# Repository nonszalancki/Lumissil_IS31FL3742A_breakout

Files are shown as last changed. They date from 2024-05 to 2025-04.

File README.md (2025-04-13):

# Breakout board for Lumissil IS31FL3742A LED driver
Simple break out board to add a bit of colours to your project.

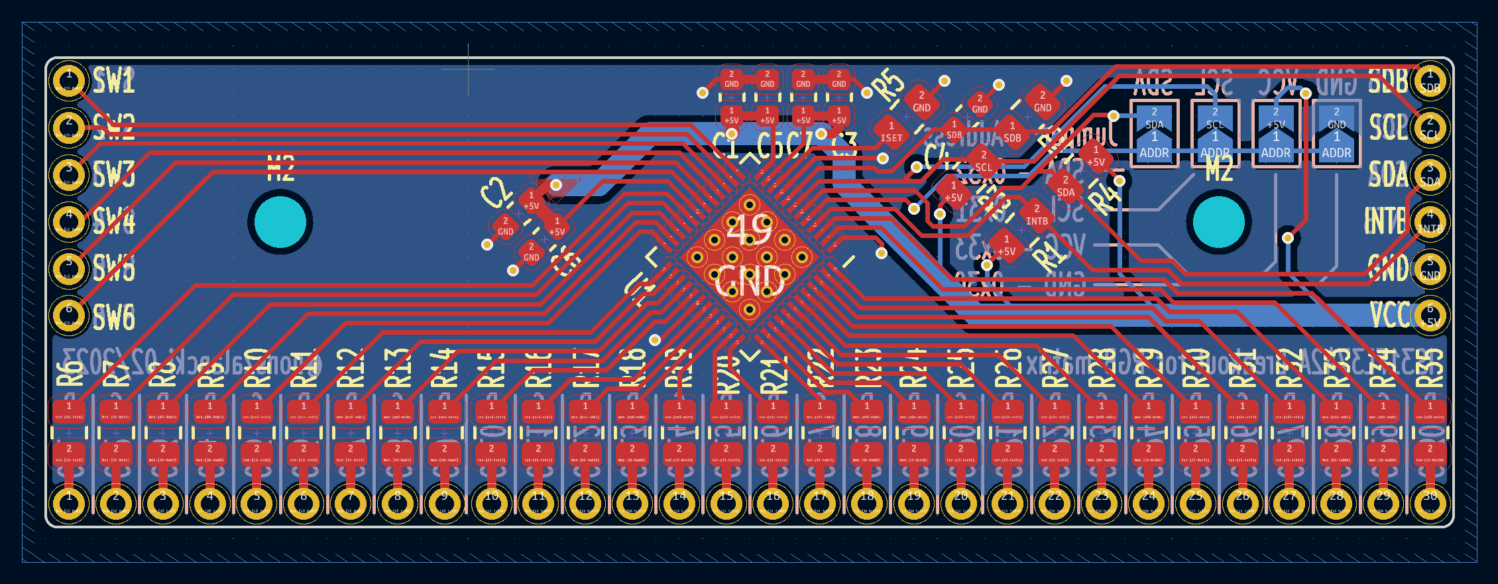
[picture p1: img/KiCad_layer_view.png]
KiCad_layer_view


## Usage/Example

keypad_qmk_test

## How to use it?
I designed these breakout boards with building rgb keyborad in mind. However you can use it in any project that you desire.
1. Download the gerber files.
2. Send them to your supplier of choice.
3. Take a look at iBOM and figure what parts you need.
4. Solder everything and connect to your microcontroller of choice. You can choose i2c address by solder pads on tha back of the breakout board.
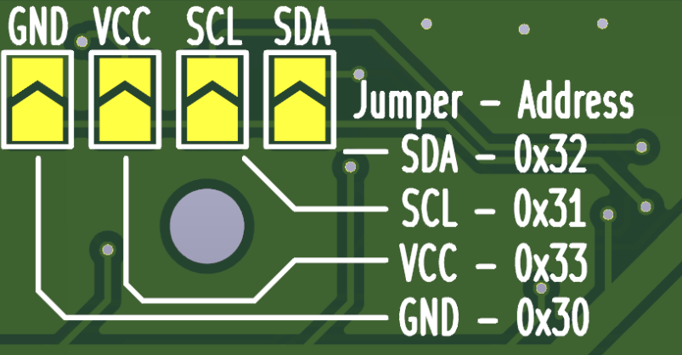
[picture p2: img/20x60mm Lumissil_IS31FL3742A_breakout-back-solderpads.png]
Lumissil_IS31FL3742A_breakout-back-solderpads

5. Enjoy!

## Building
You can use [iBOM](https://nonszalancki.github.io/Lumissil_IS31FL3742A_breakout/) here to help you with component placement.

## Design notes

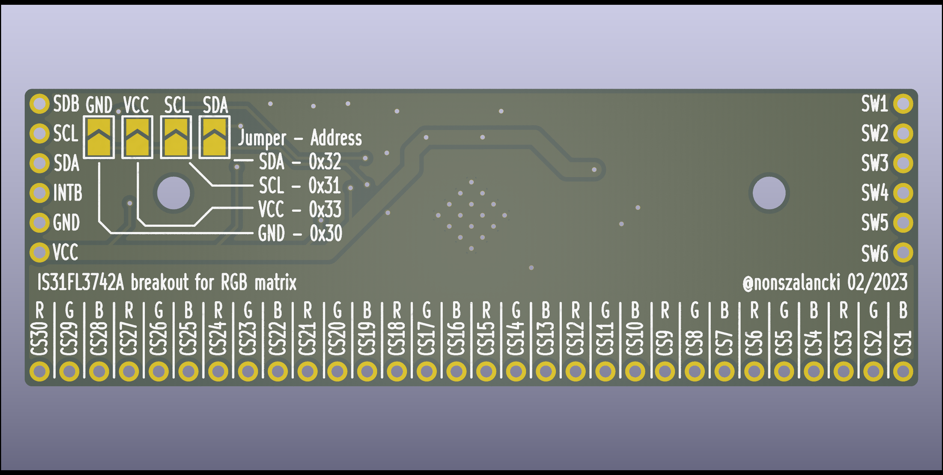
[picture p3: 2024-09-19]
img/20x60mm Lumissil_IS31FL3742A_breakout-back-rt.png

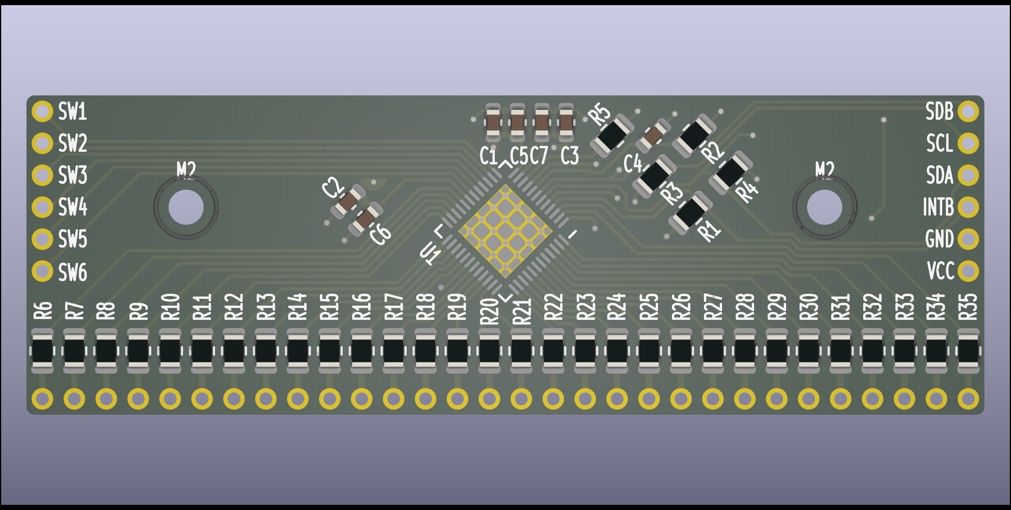
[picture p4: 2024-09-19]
img/20x60mm Lumissil_IS31FL3742A_breakout-front-rt.png

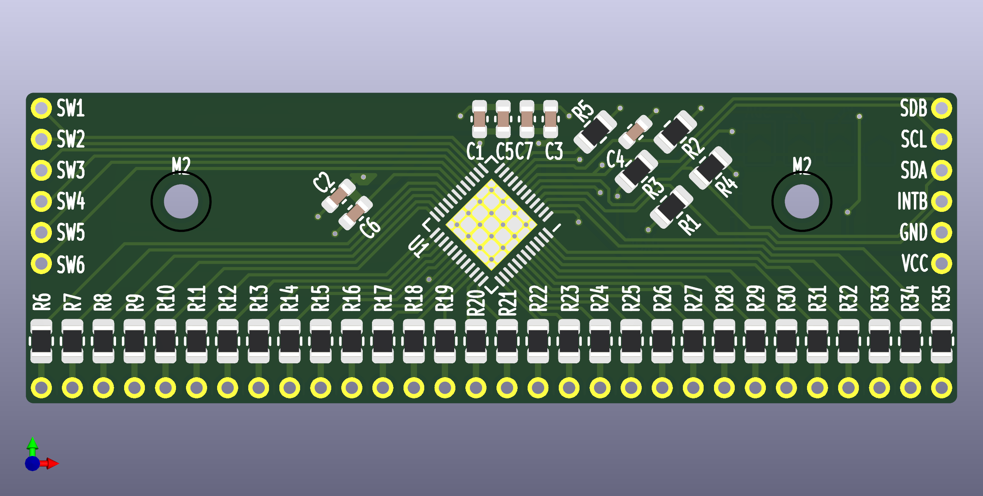
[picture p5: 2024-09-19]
img/20x60mm Lumissil_IS31FL3742A_breakout-front.png

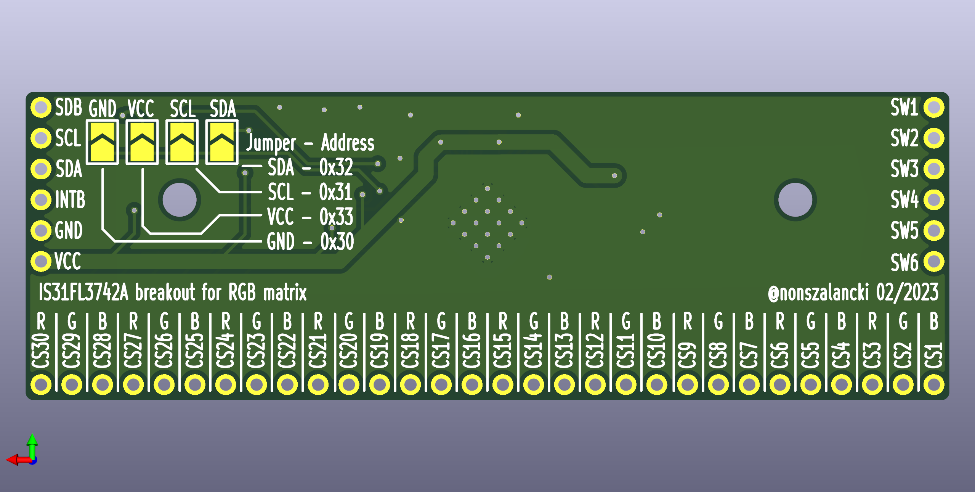
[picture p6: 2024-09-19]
img/20x60mm Lumissil_IS31FL3742A_breakout-back.png

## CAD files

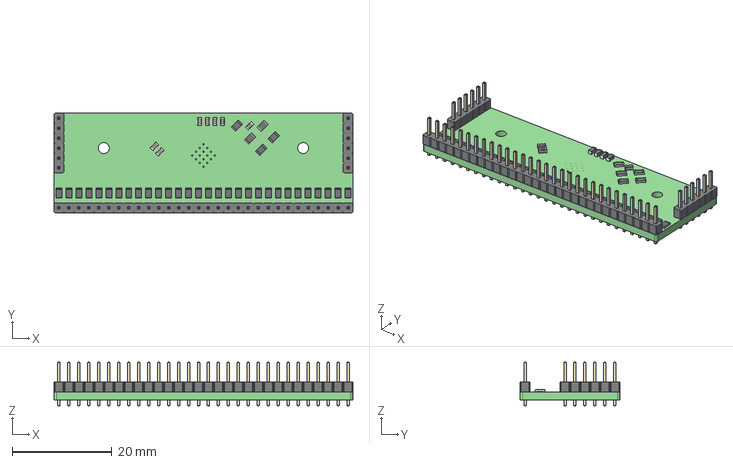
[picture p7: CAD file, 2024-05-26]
20x60mm Lumissil_IS31FL3742A_breakout/20x60mm Lumissil_IS31FL3742A_breakout.step
60.0 x 20.0 x 8.80 mm
Lumissil_IS31FL3742A_breakout PCB

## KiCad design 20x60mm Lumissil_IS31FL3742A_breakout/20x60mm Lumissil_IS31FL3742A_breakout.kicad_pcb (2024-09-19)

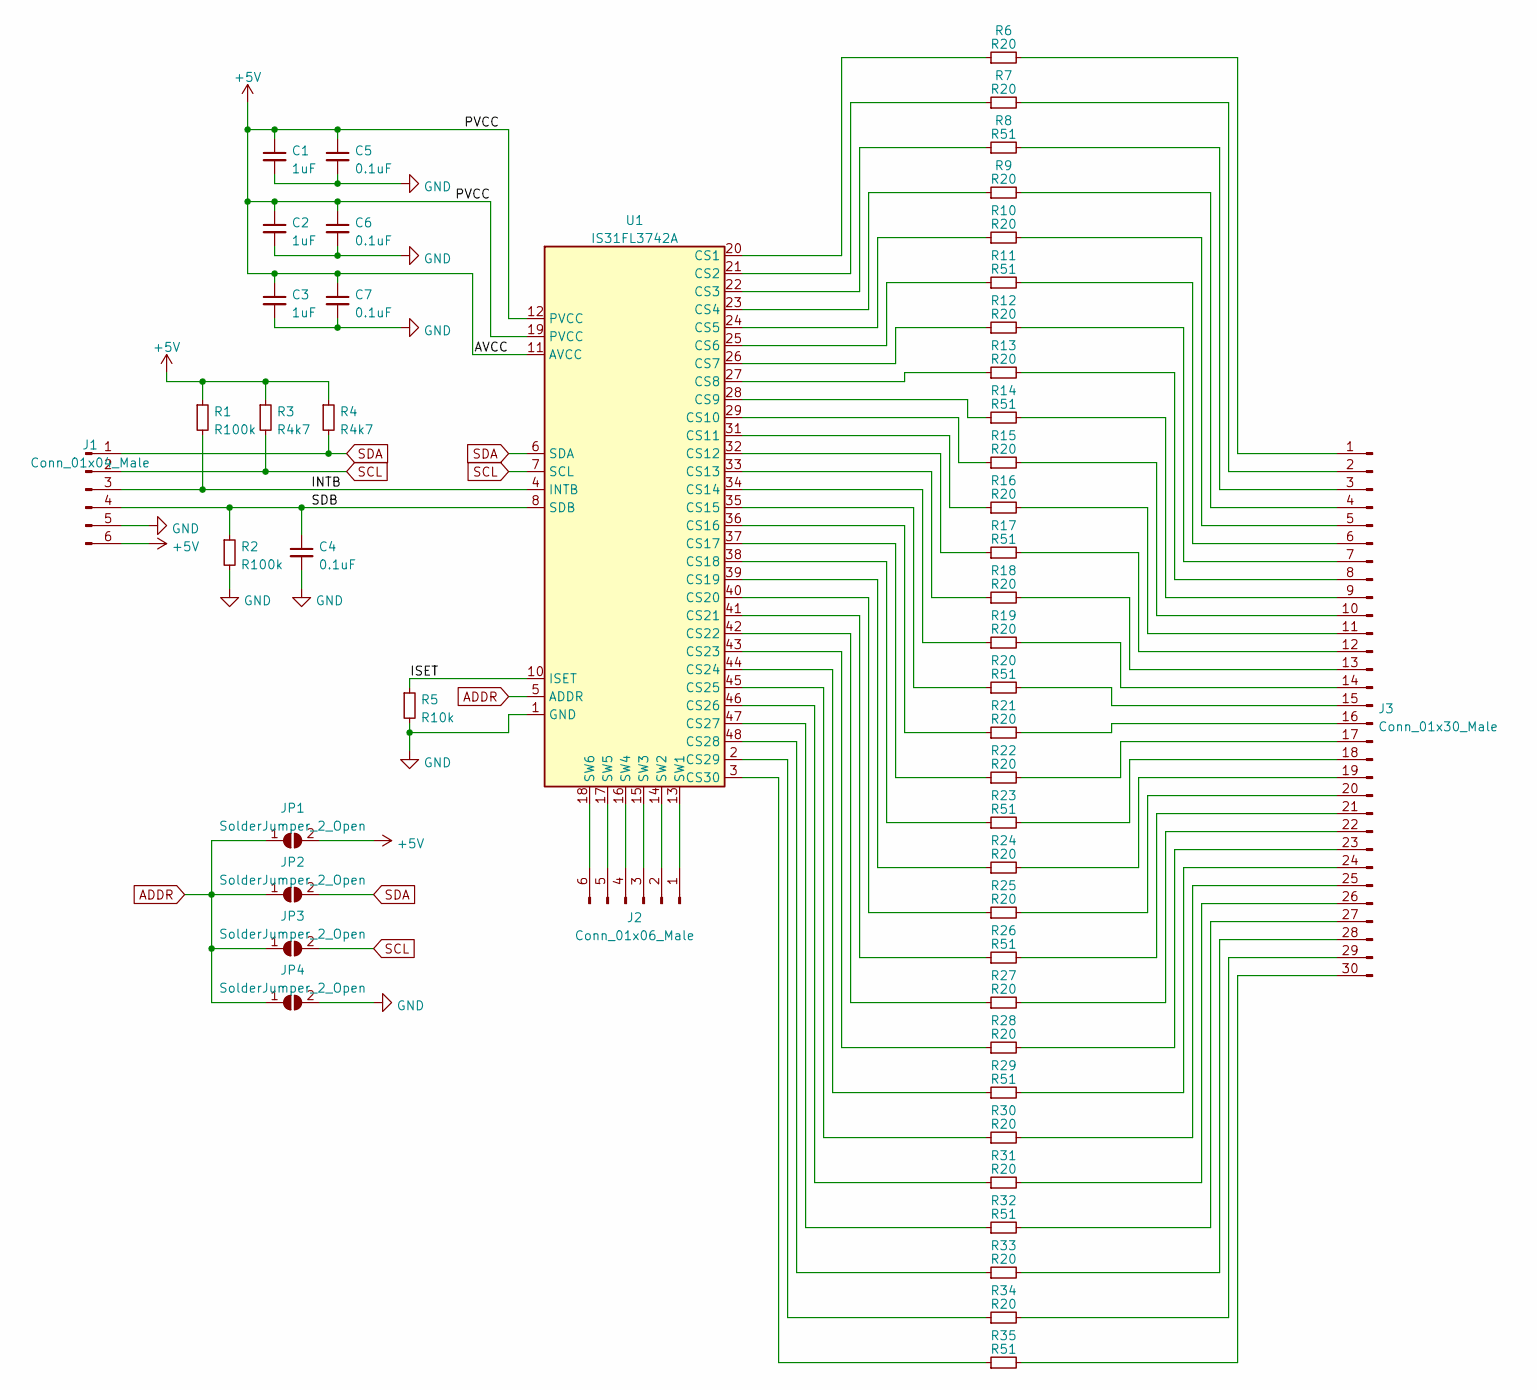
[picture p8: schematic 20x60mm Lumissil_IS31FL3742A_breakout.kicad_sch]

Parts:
C1, C2, C3: 1uF; C_0603_1608Metric
C4, C5, C6, C7: 0.1uF; C_0603_1608Metric
J1: Conn_01x04_Male; PinHeader_1x06_P2.00mm_Vertical
J2: Conn_01x06_Male; PinHeader_1x06_P2.00mm_Vertical
J3: Conn_01x30_Male; PinHeader_1x30_P2.00mm_Vertical
JP1, JP2, JP3, JP4: SolderJumper_2_Open; SolderJumper-2_P1.3mm_Open_TrianglePad1.0x1.5mm
R1, R2: R100k; R_0805_2012Metric
R3, R4: R4k7; R_0805_2012Metric
R5: R10k; R_0805_2012Metric
R6, R7, R9, R10, R12, R13, R15, R16, R18, R19, R21, R22, R24, R25, R27, R28, R30, R31, R33, R34: R20; R_0805_2012Metric
R8, R11, R14, R17, R20, R23, R26, R29, R32, R35: R51; R_0805_2012Metric
U1: IS31FL3742A; QFN-48-1EP_6x6mm_P0.4mm_EP4.2x4.2mm_ThermalVias

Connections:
+5V: C1.1, C2.1, C3.1, C5.1, C6.1, C7.1, J1.6, JP1.2 (B), R1.1, R3.1, R4.1, U1.11 (AVCC), U1.12 (PVCC), U1.19 (PVCC); also elsewhere on the board
/ISET: R5.1, U1.10 (ISET)
ADDR: JP1.1 (A), JP2.1 (A), JP3.1 (A), JP4.1 (A), U1.5 (ADDR); also elsewhere on the board
GND: C1.2, C2.2, C3.2, C4.2, C5.2, C6.2, C7.2, J1.5, JP4.2 (B), R2.2, R5.2, U1.1 (GND), U1.9 (GND), U1.30 (GND), U1.49 (GND); also elsewhere on the board
unnamed: J2.1, U1.13 (SW1)
unnamed: J2.2, U1.14 (SW2)
unnamed: J2.3, U1.15 (SW3)
unnamed: J2.4, U1.16 (SW4)
unnamed: J2.5, U1.17 (SW5)
unnamed: J2.6, U1.18 (SW6)
unnamed: J3.1, R6.2
unnamed: J3.2, R7.2
unnamed: J3.3, R8.2
unnamed: J3.4, R9.2
unnamed: J3.5, R10.2
unnamed: J3.6, R11.2
unnamed: J3.7, R12.2
unnamed: J3.8, R13.2
unnamed: J3.9, R14.2
unnamed: J3.10, R15.2
unnamed: J3.11, R16.2
unnamed: J3.12, R17.2
unnamed: J3.13, R18.2
unnamed: J3.14, R19.2
unnamed: J3.15, R20.2
unnamed: J3.16, R21.2
unnamed: J3.17, R22.2
unnamed: J3.18, R23.2
unnamed: J3.19, R24.2
unnamed: J3.20, R25.2
unnamed: J3.21, R26.2
unnamed: J3.22, R27.2
unnamed: J3.23, R28.2
unnamed: J3.24, R29.2
unnamed: J3.25, R30.2
unnamed: J3.26, R31.2
unnamed: J3.27, R32.2
unnamed: J3.28, R33.2
unnamed: J3.29, R34.2
unnamed: J3.30, R35.2
unnamed: R6.1, U1.20 (CS1)
unnamed: R7.1, U1.21 (CS2)
unnamed: R8.1, U1.22 (CS3)
unnamed: R9.1, U1.23 (CS4)
unnamed: R10.1, U1.24 (CS5)
unnamed: R11.1, U1.25 (CS6)
unnamed: R12.1, U1.26 (CS7)
unnamed: R13.1, U1.27 (CS8)
unnamed: R14.1, U1.28 (CS9)
unnamed: R15.1, U1.29 (CS10)
unnamed: R16.1, U1.31 (CS11)
unnamed: R17.1, U1.32 (CS12)
unnamed: R18.1, U1.33 (CS13)
unnamed: R19.1, U1.34 (CS14)
unnamed: R20.1, U1.35 (CS15)
unnamed: R21.1, U1.36 (CS16)
unnamed: R22.1, U1.37 (CS17)
unnamed: R23.1, U1.38 (CS18)
unnamed: R24.1, U1.39 (CS19)
unnamed: R25.1, U1.40 (CS20)
unnamed: R26.1, U1.41 (CS21)
unnamed: R27.1, U1.42 (CS22)
unnamed: R28.1, U1.43 (CS23)
unnamed: R29.1, U1.44 (CS24)
unnamed: R30.1, U1.45 (CS25)
unnamed: R31.1, U1.46 (CS26)
unnamed: R32.1, U1.47 (CS27)
unnamed: R33.1, U1.48 (CS28)
unnamed: R34.1, U1.2 (CS29)
unnamed: R35.1, U1.3 (CS30)
SCL: J1.2, JP3.2 (B), R3.2, U1.7 (SCL); also elsewhere on the board

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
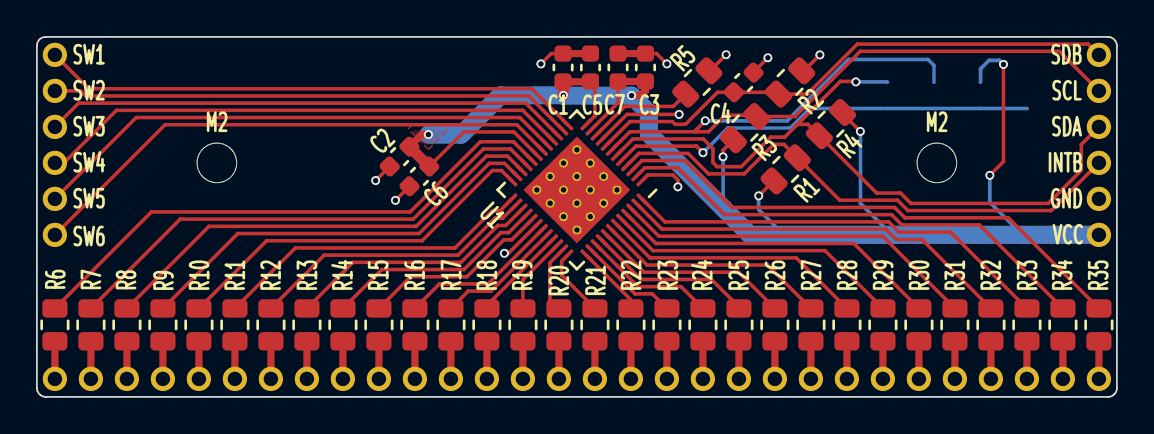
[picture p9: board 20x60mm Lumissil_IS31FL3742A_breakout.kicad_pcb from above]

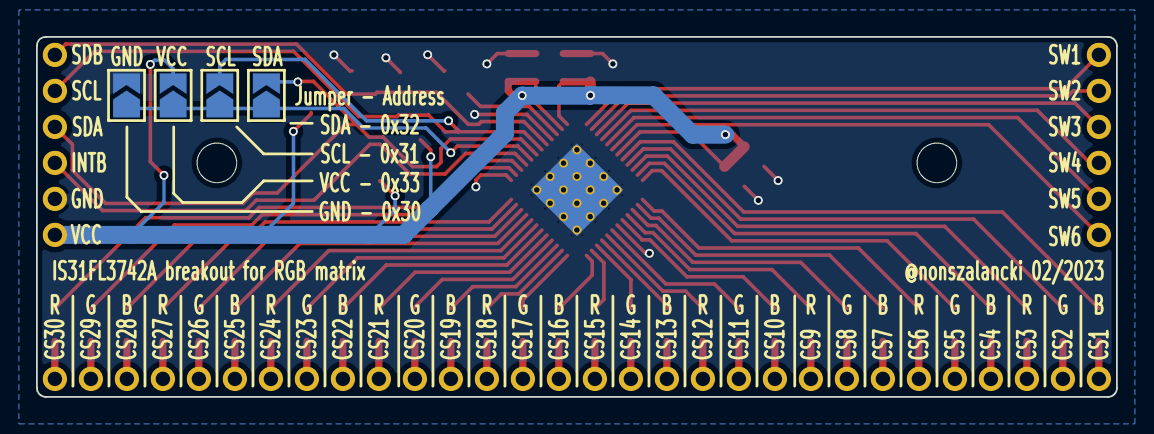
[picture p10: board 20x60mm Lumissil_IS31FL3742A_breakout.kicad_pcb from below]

Board: 2 copper layers, 60.0 x 20.0 mm, 52 parts (4 on the bottom side), 74 nets.

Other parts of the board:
GND: SolderJumper_2_Open; SolderJumper-2_P1.3mm_Open_TrianglePad1.0x1.5mm
M2, M2#2: MountingHole_2.2mm_M2_DIN965
SCL: SolderJumper_2_Open; SolderJumper-2_P1.3mm_Open_TrianglePad1.0x1.5mm
SDA: SolderJumper_2_Open; SolderJumper-2_P1.3mm_Open_TrianglePad1.0x1.5mm
VCC: SolderJumper_2_Open; SolderJumper-2_P1.3mm_Open_TrianglePad1.0x1.5mm

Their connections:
+5V: VCC.2 (B); also elsewhere on the board
ADDR: GND.1 (A), SCL.1 (A), SDA.1 (A), VCC.1 (A); also elsewhere on the board
GND: GND.2 (B); also elsewhere on the board
SCL: SCL.2 (B); also elsewhere on the board

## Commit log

2024-09-19 added more img
    [20x60mm Lumissil_IS31FL3742A_breakout.kicad_pcb]
2024-09-19 added solderpads png
